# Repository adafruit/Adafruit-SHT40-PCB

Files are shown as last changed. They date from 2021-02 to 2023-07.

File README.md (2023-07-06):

## Adafruit SHT40, SHT41, and SHT45 Temperature & Humidity Sensor PCBs

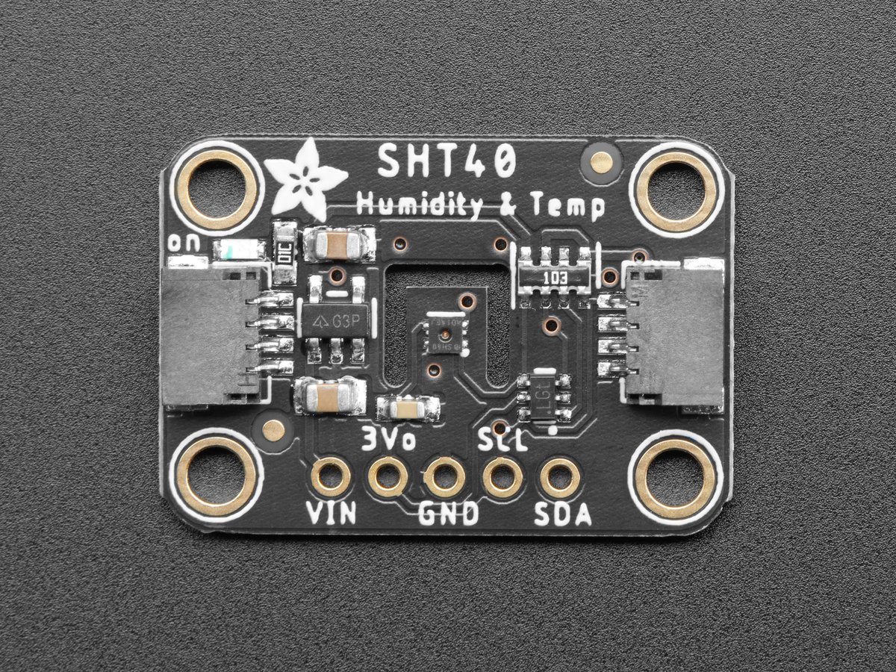
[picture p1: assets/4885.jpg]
<a href="http://www.adafruit.com/products/4885"><br/>
Click here to purchase the SHT40 from the Adafruit shop</a>

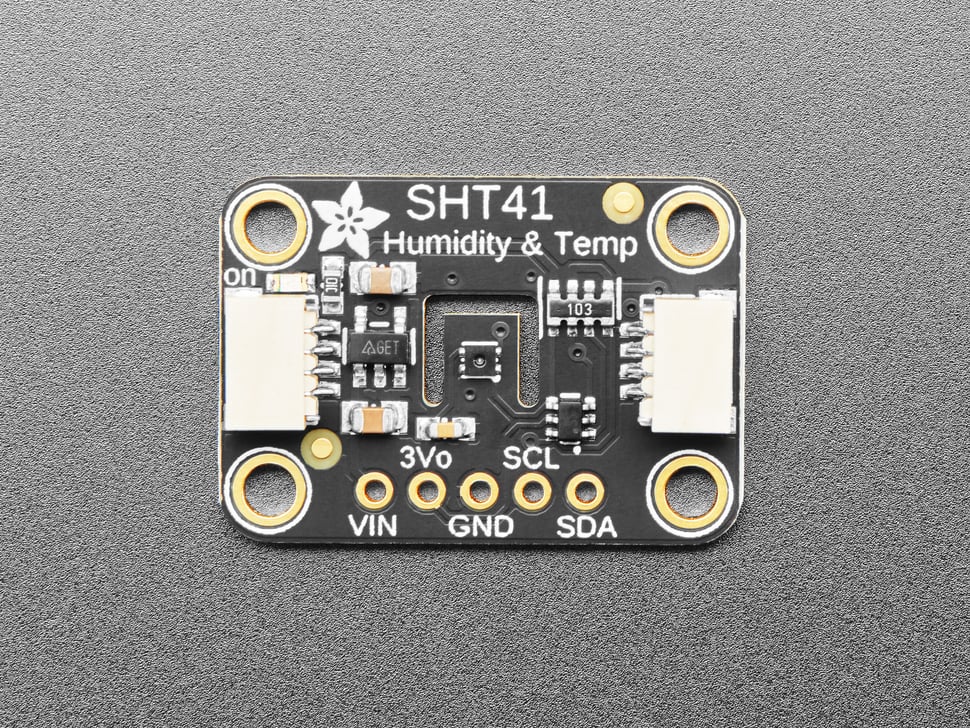
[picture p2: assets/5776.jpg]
<a href="http://www.adafruit.com/products/5776"><br/>
Click here to purchase the SHT41 from the Adafruit shop</a>

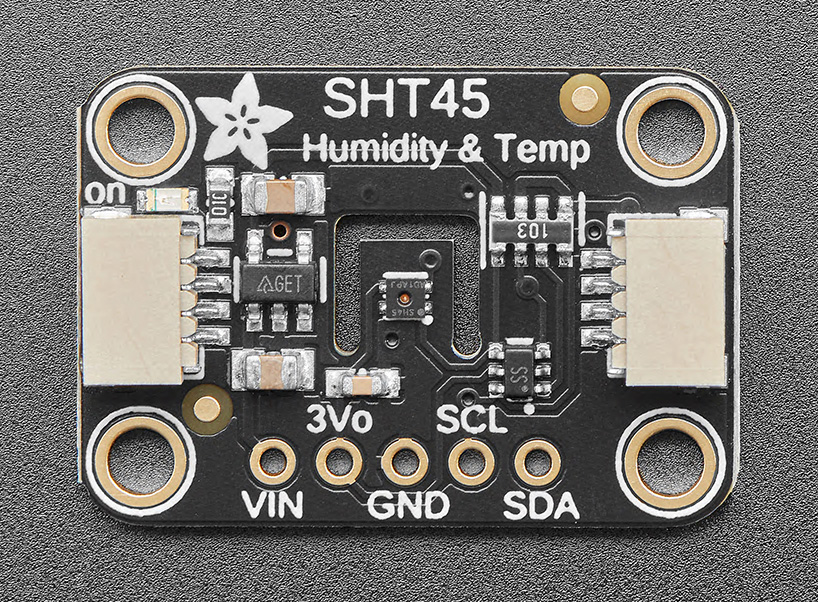
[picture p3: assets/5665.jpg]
<a href="http://www.adafruit.com/products/5665"><br/>
Click here to purchase the SHT45 from the Adafruit shop</a>

PCB files for the Adafruit SHT40, SHT41, and SHT45 Temperature & Humidity Sensors. 

Format is EagleCAD schematic and board layout
* https://www.adafruit.com/product/4885
* https://www.adafruit.com/product/5665
* https://www.adafruit.com/product/5776

### Description

Sensirion Temperature/Humidity sensors are some of the finest & highest-accuracy devices you can get. And finally, we have some that have a true I2C interface for easy reading. The SHT40, SHT41, and SHT45 sensors are the fourth generation (started at the SHT10 and worked its way up to the top!).

The SHT40 has an excellent ±1.8% typical relative humidity accuracy from 25 to 75% and ±0.2 °C typical accuracy from 0 to 75 °C.

The SHT41 has an excellent ±1.8% typical relative humidity accuracy from 25 to 75% and ±0.2 °C typical accuracy from 0 to 75 °C.

The SHT45 has an even more excellent ±1% typical relative humidity accuracy from 25 to 75% and ±0.1 °C typical accuracy from 0 to 75 °C.

Other than these differences in relative humidity and temperature accuracy, there is no discernible difference between these two chips. The I2C addresses and code are identical for both. So, how do you know which one you have? The text on the board indicates which breakout you have.

Unlike some earlier SHT sensors, this sensor has a true I2C interface for easy interfacing with only two wires (plus power and ground!). Thanks to the voltage regulator and level shifting circuitry we've included on the breakout It is also is 3V or 5V compliant, so you can power and communicate with it using any microcontroller or microcomputer.

Such a lovely chip - so we spun up a breakout board with the SHT4x and some supporting circuitry such as pullup resistors and capacitors. To make things even easier, we've included SparkFun Qwiic compatible STEMMA QT connectors for the I2C bus so you don't even need to solder! QT Cable is not included, but we have a variety in the shop.

If you prefer working on a breadboard, each order comes with one fully assembled and tested PCB breakout and a small piece of header. You'll need to solder the header onto the PCB, but it's fairly easy and takes only a few minutes even for a beginner.

We've written both Arduino and CircuitPython/Python library code for this chip, so you can use it with just about any microcontroller or single-board computer like Raspberry Pi.

### License

Adafruit invests time and resources providing this open source design, please support Adafruit and open-source hardware by purchasing products from [Adafruit](https://www.adafruit.com)!

Designed by Limor Fried/Ladyada for Adafruit Industries.

Creative Commons Attribution/Share-Alike, all text above must be included in any redistribution. 
See license.txt for additional details.

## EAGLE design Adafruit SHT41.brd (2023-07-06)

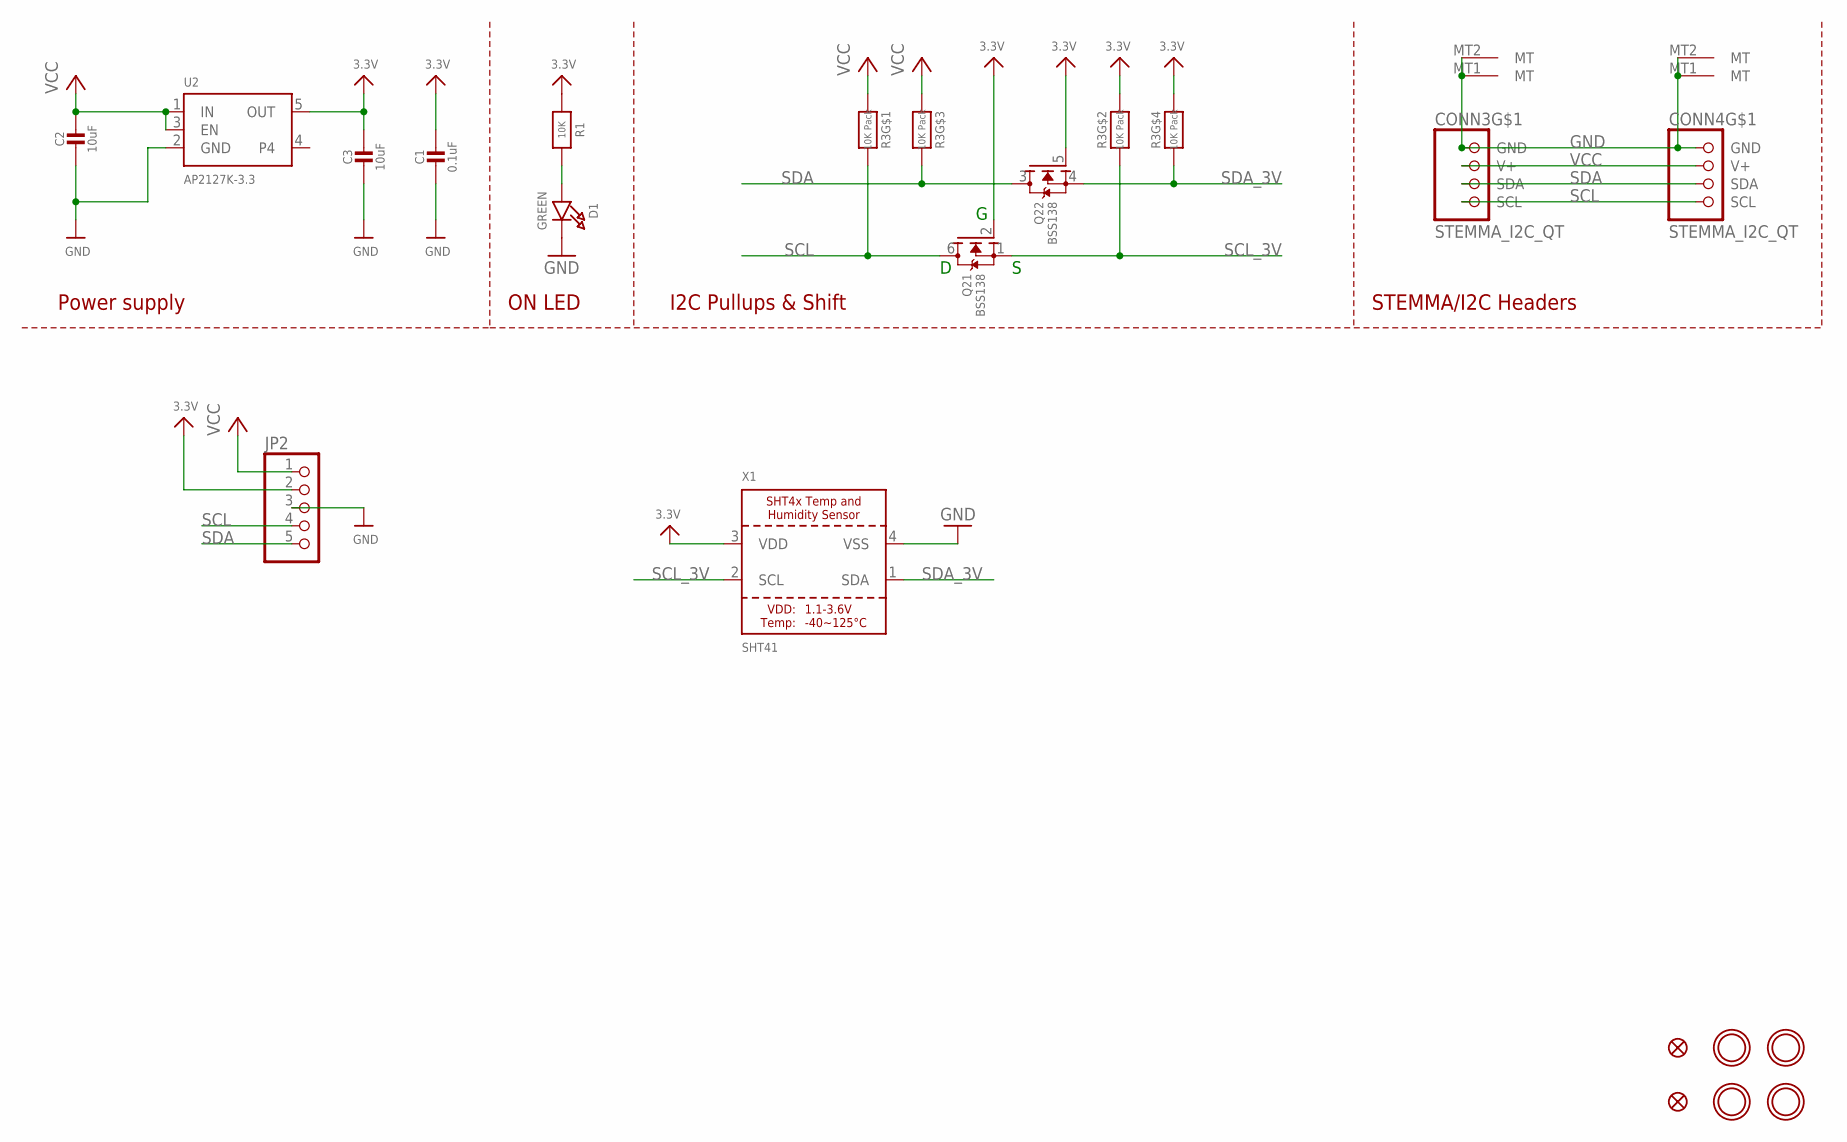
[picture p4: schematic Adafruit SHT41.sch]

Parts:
C1: 0.1uF; 0603-NO
C2, C3: 10uF; 0805-NO
CONN3, CONN4: STEMMA_I2C_QT; JST_SH4
D1: GREEN; CHIPLED_0603_NOOUTLINE
FID3, FID4: FIDUCIAL_1MM
JP2: HEADER-1X570MIL; 1X05_ROUND_70
Q2: BSS138; SOT363
R1: 10K; 0603-NO
R3: 10K Pack; RESPACK_4X0603
U2: AP2127K-3.3; SOT23-5
U$1, U$17, U$19, U$21: MOUNTINGHOLE2.5; MOUNTINGHOLE_2.5_PLATED
X1: SHT41; SHT4X

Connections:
3.3V: C1.1, C3.1, JP2.2, Q2.2 (G), Q2.5 (G), R1.1, R3.2 (1), R3.4 (1), U2.5 (OUT), X1.3 (VDD)
GND: C1.2, C2.2, C3.2, CONN3.1 (GND), CONN3.MT1 (MT), CONN3.MT2 (MT), CONN4.1 (GND), CONN4.MT1 (MT), CONN4.MT2 (MT), D1.C, JP2.3, U2.2 (GND), X1.4 (VSS)
unnamed: D1.A, R1.2
SCL: CONN3.4 (SCL), CONN4.4 (SCL), JP2.4, Q2.6 (D), R3.8 (2)
SCL_3V: Q2.1 (S), R3.7 (2), X1.2 (SCL)
SDA: CONN3.3 (SDA), CONN4.3 (SDA), JP2.5, Q2.3 (D), R3.6 (2)
SDA_3V: Q2.4 (S), R3.5 (2), X1.1 (SDA)
VCC: C2.1, CONN3.2 (V+), CONN4.2 (V+), JP2.1, R3.1, R3.3 (1), U2.1 (IN), U2.3 (EN)

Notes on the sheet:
I2C Pullups & Shift
STEMMA/I2C Headers
ON LED
Power supply

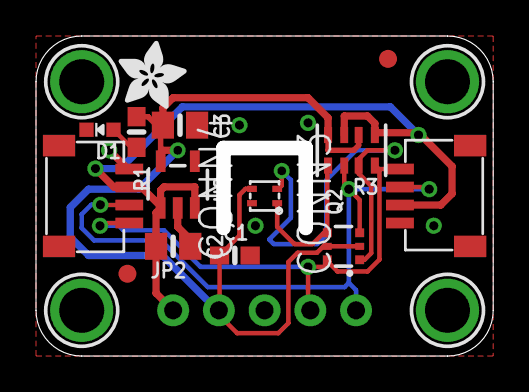
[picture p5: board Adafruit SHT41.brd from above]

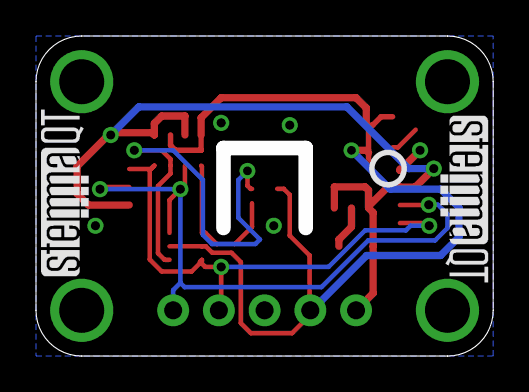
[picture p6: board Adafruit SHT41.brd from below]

Board: 2 copper layers, 25.4 x 17.8 mm, 35 parts (8 on the bottom side), 8 nets.

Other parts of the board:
PLABEL0: PLABEL0
PLABEL1: PLABEL1
PLABEL2: PLABEL2
PLABEL3: PLABEL3
PLABEL4: PLABEL4
PLABEL7: PLABEL7
PLABEL8: PLABEL8
PLABEL9: PLABEL9
PLABEL10: PLABEL10
PLABEL11: PLABEL11
PLABEL12: PLABEL12
PLABEL13: PLABEL13
PLABEL14: PLABEL14
U$22: ADAFRUIT_3.5MM
U$25: PCBFEAT-REV-040
U$30, U$31: STEMMAQT

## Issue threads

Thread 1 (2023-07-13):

sht45 disable LED pads

hayc, 2023-07-13:
Please add traces and solder pads to disable the power LED. This was done recently for https://www.adafruit.com/product/4821

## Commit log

2021-02-03 Adding board files.
    [Adafruit SHT40.brd, Adafruit SHT40.sch]
2023-01-13 Add new board files.
    [Adafruit SHT45.brd, Adafruit SHT45.sch]
2023-07-06 Add board files.
    [Adafruit SHT41.brd, Adafruit SHT41.sch]

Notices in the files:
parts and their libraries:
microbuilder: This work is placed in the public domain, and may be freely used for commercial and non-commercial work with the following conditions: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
